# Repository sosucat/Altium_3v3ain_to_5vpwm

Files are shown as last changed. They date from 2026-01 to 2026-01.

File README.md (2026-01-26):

# Altium_3v3ain_to_5vpwm
Altium project files for a 3.3V analog to 5V pwm (4kHz) convertor using [LTC6992-1](https://www.analog.com/media/en/technical-documentation/data-sheets/LTC6992-1-6992-2-6992-3-6992-4.pdf).
This enables 3.3V ILDA DACs (e.g., [Helios DAC](https://bitlasers.com/helios-laser-dac/)) to control PWM-based industry lasers.
For 5V-based ILDA DACs, you want to look for commercially-available 5V analog-pwm converters.

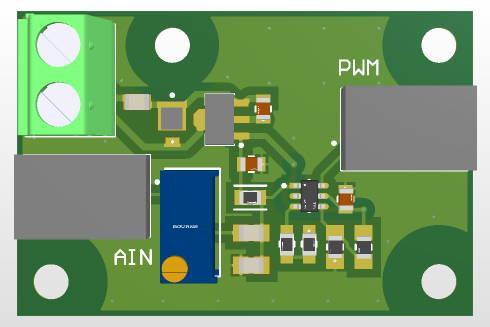
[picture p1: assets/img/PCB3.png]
A rendered image of the circuit board


### LTC6992-1
LTC6992-1 linearly maps a 0.1-0.9V analog input to a 0-100% duto-cycle pwm signal. The output pwm frequency can be set between 3.81Hz and 1MHz by adusting the resistor values (R_SET, R1, and R2). To identify these values for your desired output frequency, you want to first decide N_dev, referring to the table [here](https://www.analog.com/media/en/technical-documentation/data-sheets/LTC6992-1-6992-2-6992-3-6992-4.pdf#page=16). Once you decide on N_dev, the table gives you the R1 and R2 values, and you can obtain the corresopnding R_SET value using Equation (1b) on [this page](https://www.analog.com/media/en/technical-documentation/data-sheets/LTC6992-1-6992-2-6992-3-6992-4.pdf#page=20).

### PCB Overview & Usage
This pcb scales a 3.3V analog signal to a 0.1-0.9V one using a resistor network. Then, the LTC6992-1 converts it into a 4kHz 5V pwm signal.
- INPUT: 0-3.3V analog; JST-XH terminal.
- VIN: 12-24V DC; Terminal block. The LDO regulates it to 5V (VDD). Current spike protection with a series resistor and a zener diode.
- OUTPUT: 5V 4kHz pwm (AIN=0V -> OUT=0%; AIN=5V -> OUT=100%. Linearly mapped); JST-XH terminal.
- Calibration: The analog--duty-cycle gain is adjustable with the potentiometer to compensate the voltage drop over the analog wires.
  - Connect the power supply and analog signal lines.
  - Send the maximum analog signal (i.e., 3.3V).
  - Twist the potentiometer so that the measured voltage at Pin 1 (MOD) of LTC6992-1 is about 0.9V.
  - Set the analog input to the lowest (i.e., 0.0V) and check the Pin 1 voltage is below 0.1V. No need to twist the pot this time. This will ensure the 0% duty cycle for the lowest analog voltage.
- DigiKey component list
  - https://www.digikey.com/en/mylists/list/5BIYH8LDG3
  - https://www.digikey.com/en/mylists/list/SE503POLSQ (additional components for the 3.3V version)

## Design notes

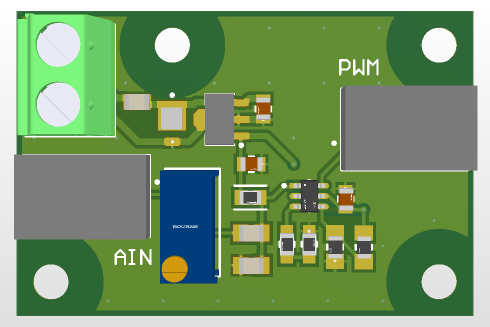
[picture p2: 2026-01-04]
assets/img/PCB2.png

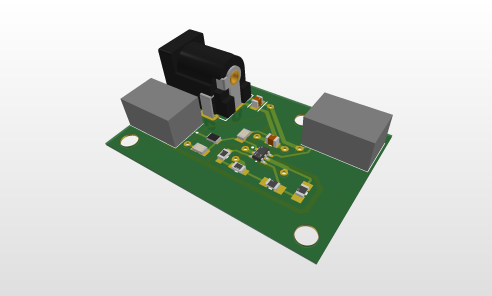
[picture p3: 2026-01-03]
assets/img/PCB1.png

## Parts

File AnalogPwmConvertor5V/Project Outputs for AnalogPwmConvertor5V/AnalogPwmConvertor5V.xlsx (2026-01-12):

Line # | Name | Description | Designator | Revision ID | Revision State | Revision Status | Quantity | Manufacturer 1 | Manufacturer Part Number 1 | Manufacturer Lifecycle 1 | Supplier 1 | Supplier Part Number 1 | Supplier Unit Price 1 | Supplier Subtotal 1
1 | 1729128 | PCB Terminal Block, 13.5 A, 400 V, 2-Pin THD, RoHS, Bulk | 24V | CMP-2000-05815-1 | Released | Up to date | 1 | Phoenix Contact | 1729128 | Volume Production | Arrow Electronics | 1729128 | 0.8797 | 0.8797
2 | S2B-XH-A(LF)(SN) | Male Header, Pitch 2.5 mm, 1 x 2 Position, Height 6.1 mm, Tail Length 3.4 mm, -25 to 85 degC, RoHS, Bulk | AIN, PWM | CMP-1755-00005-1 | Released | Up to date | 2 | JST | S2B-XH-A(LF)(SN) | Volume Production | Arrow Electronics | S2B-XH-A(LF)(SN) | 0.0697 | 0.1394
3 | GCM21BR72A104KA37L | Ceramic Capacitor for Automotive 100nF ±10% 100VDC X7R 0805 Embossed T/R | C_DPL1, C_OUT | CMP-2007-03364-2 | New From Design | Up to date | 2 | Murata | GCM21BR72A104KA37L | Volume Production | Mouser | 81-GCM21BR72A104KA7L | 0.14 | 0.28
4 | GCM219R71H334KA55D | Ceramic Capacitor for Automotive 330nF ±10% 50VDC X7R 0805 Paper T/R | C_IN | CMP-2007-00092-2 | New From Design | Up to date | 1 | Murata | GCM219R71H334KA55D | Volume Production | Mouser | 81-GCM219R71H334KA5D | 0.25 | 0.25
5 | 1PMT5935BT1G | 3.2 W Plastic Surface Mount, 2-Pin POWERMITE, Pb-Free, Tape and Reel | D1 | CMP-1060-00053-1 | Released | Up to date | 1 | onsemi | 1PMT5935BT1G | Volume Production | Arrow Electronics | 1PMT5935BT1G | 0.1859 | 0.1859
6 | RG2012P-105-B-T5 | Automotive Metal Thin Film Chip Resistor, 0805, 1MΩ, 0.1%, 25ppm/°C, 0.125W, 150V | R1 | CMP-2001-02713-2 | Released | Up to date | 1 | Susumu | RG2012P-105-B-T5 | Volume Production | Mouser | 754-RG2012P-105-B-T5 | 0.1 | 0.1
7 | RG2012P-2803-B-T5 | Automotive Metal Thin Film Chip Resistor, 0805, 280kΩ, 0.1%, 25ppm/°C, 0.125W, 150V | R2 | CMP-2001-02887-2 | Released | Up to date | 1 | Susumu | RG2012P-2803-B-T5 | Volume Production | Newark | RG2012P-2803-B-T5 | 0.019 | 0.019
8 | ERA6AEB472V |  | R_AIN | CMP-2001-00644-1 | Released | Up to date | 1 | Panasonic | ERA-6AEB472V | Volume Production | Mouser | 667-ERA-6AEB472V | 0.12 | 0.12
9 | ERA-6AEB104V | RES 100K OHM 0.1% 1/8W 0805 | R_BIAS | CMP-2001-00583-2 | Released | Up to date | 1 | Panasonic | ERA-6AEB104V | Volume Production | Future Electronics | 3098727 | 0.205 | 0.205
10 | ERA6AEB202V |  | R_G | CMP-2001-00609-1 | Released | Up to date | 1 | Panasonic | ERA-6AEB202V | Volume Production | Mouser | 667-ERA-6AEB202V | 0.1 | 0.1
11 | 3296W-1-202LF | TRIMMER 2K OHM 0.5W PC PIN TOP | R_POT | CMP-2000-05582-2 | Released | Up to date | 1 | Bourns | 3296W-1-202LF | Volume Production | Avnet | 3296W-1-202LF | 1.96 | 1.96
12 | ERA-6AEB154V | RES 150K OHM 0.1% 1/8W 0805 | R_SET1 | CMP-2001-00599-2 | Released | Up to date | 1 | Panasonic | ERA-6AEB154V | Volume Production | Mouser | 667-ERA-6AEB154V | 0.1 | 0.1
13 | ERA-6AEB473V |  | R_SET2 | CMP-2001-00645-2 | Released | Up to date | 1 | Panasonic | ERA-6AEB473V | Volume Production | Avnet | 08N2176 | 0.102 | 0.102
14 | ERA6AEB331V |  | R_VIN | CMP-2001-00628-1 | Released | Up to date | 1 | Panasonic | ERA-6AEB331V | Volume Production | Arrow Electronics | ERA-6AEB331V | 0.0322 | 0.0322
15 | LTC6992MPS6-1#TRMPBF | IC OSC SILICON PROG TSOT23-6 | U1 | CMP-09075-000003-1 | New From Design | Up to date | 1 | Analog Devices | LTC6992MPS6-1#TRMPBF | Volume Production | Newark | LTC6992MPS6-1#TRMPBF | 14.51 | 14.51
16 | L78L05ABUTR | Positive Voltage Regulator, 5V, 4-Pin SOT-89, Tape and Reel | U2 | CMP-0244-00406-1 | Released | Up to date | 1 | STMicroelectronics | L78L05ABUTR | Volume Production | Mouser | 511-L78L05ABU | 0.24 | 0.24

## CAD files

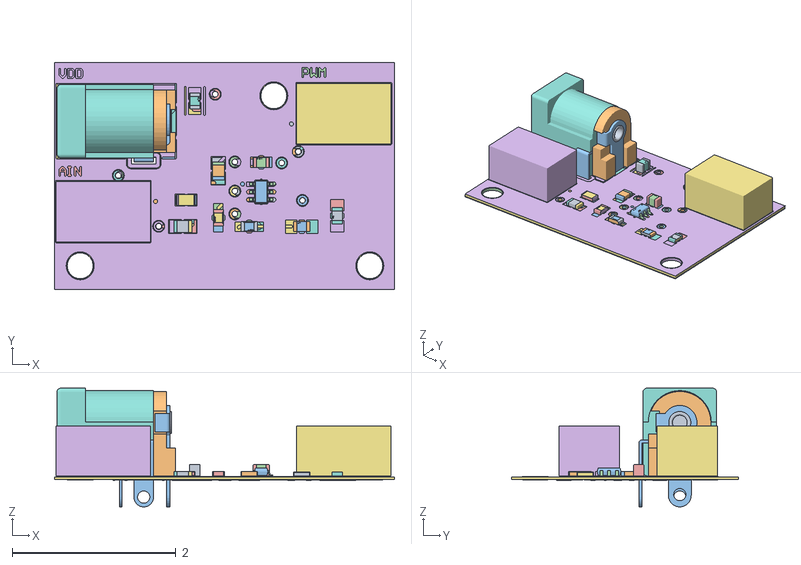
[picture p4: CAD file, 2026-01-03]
AnalogPwmConvertor5V/PCB1.obj
4.15 x 2.77 x 1.45
Silk.1
Silk.2
Silk.3
Silk.4
Silk.5
Silk.6
Silk.7
Silk.8
Silk.9
Silk.10
Silk.11
Silk.12
Silk.13
Silk.14
Silk.15
Silk.16
Silk.17
Silk.18
Silk.19
Silk.20
Silk.21
Silk.22
Silk.23
Silk.24
Silk.25
Silk.26
Silk.27
Silk.28
Silk.29
Silk.30
Silk.31
Silk.32
Silk.33
Silk.34
Silk.35
Silk.36
Silk.37
Silk.38
ComponentBody
ComponentBody.1
ComponentBody.2
ComponentBody.3
ComponentBody.4
ComponentBody.5
ComponentBody.6
ComponentBody.7
ComponentBody.8
ComponentBody.9
ComponentBody.10
ComponentBody.11
ComponentBody.12
ComponentBody.13
ComponentBody.14
ComponentBody.15
ComponentBody.16
ComponentBody.17
ComponentBody.18
ComponentBody.19
ComponentBody.20
ComponentBody.21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

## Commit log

2026-01-01 Initial commit with the Altium project files
    [AnalogPwmConvertor5V.PrjPcb, PCB1.PcbDoc, Sheet1.SchDoc]
2026-01-02 Finished routing, holes, and board shape.
    [PCB1.PcbDoc]
2026-01-03 Added a rendered image
    [PCB1.PcbDoc, PCB1.obj]
2026-01-04 Updated for 3.3V AIN; Added input over-current protection; Poured ground for shielding from PWM; Added vias at the ground pins and blank ground planes; Thermal relief at the ground pins
    [AnalogPwmConvertor5V.PrjPcb, PCB1.PcbDoc, Sheet1.SchDoc]
2026-01-12 Increased the inter-trace clearance for safer fabrication.
    [AnalogPwmConvertor5V.PrjPcb, AnalogPwmConvertor5V.xlsx, PCB1.PcbDoc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]
2026-01-12 just in case
    [PCB1.PcbDoc]
